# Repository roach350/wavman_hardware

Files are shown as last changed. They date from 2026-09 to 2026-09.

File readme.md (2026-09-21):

# WAVMAN Hardware
## WAVMAN Overview
WAVMAN is an open source portable PCM audio player based around the ATSAMD21 serieis of microcontrollers and the PCM5102 DAC. It supports SD via an SPI interface.

## Revisions and Notes
### REV 0
- Wrong symbol for USB-C resulting in only one pair of DP/DM being connected
- DAC does not have 3.3v on VDDIO or VDDIN
- PCM_MUTE (DAC mute) is not connected to MCU or even a pull up resistor to 3.3v so DAC is always muted by default
- The hold switch was botched (not connected to MCU and wrong net for power)
- All displays sink current from the LDO instaed of the battery directly, it may be desirable to change this
- No dedicated debug port for SWCLK and SWDIO
- The audio amp. has is missing several compontents (feedback resistors Rf and decoupling cap.)
- AMP_SHUTDOWN is not connected to the MCU
### REV 1
- should fix all major issues with REV 0
- minor tweaks to switch and knob placement
- 0805 passive components
- rerouted audio ICs
- knockout silkscreen for userfacing text

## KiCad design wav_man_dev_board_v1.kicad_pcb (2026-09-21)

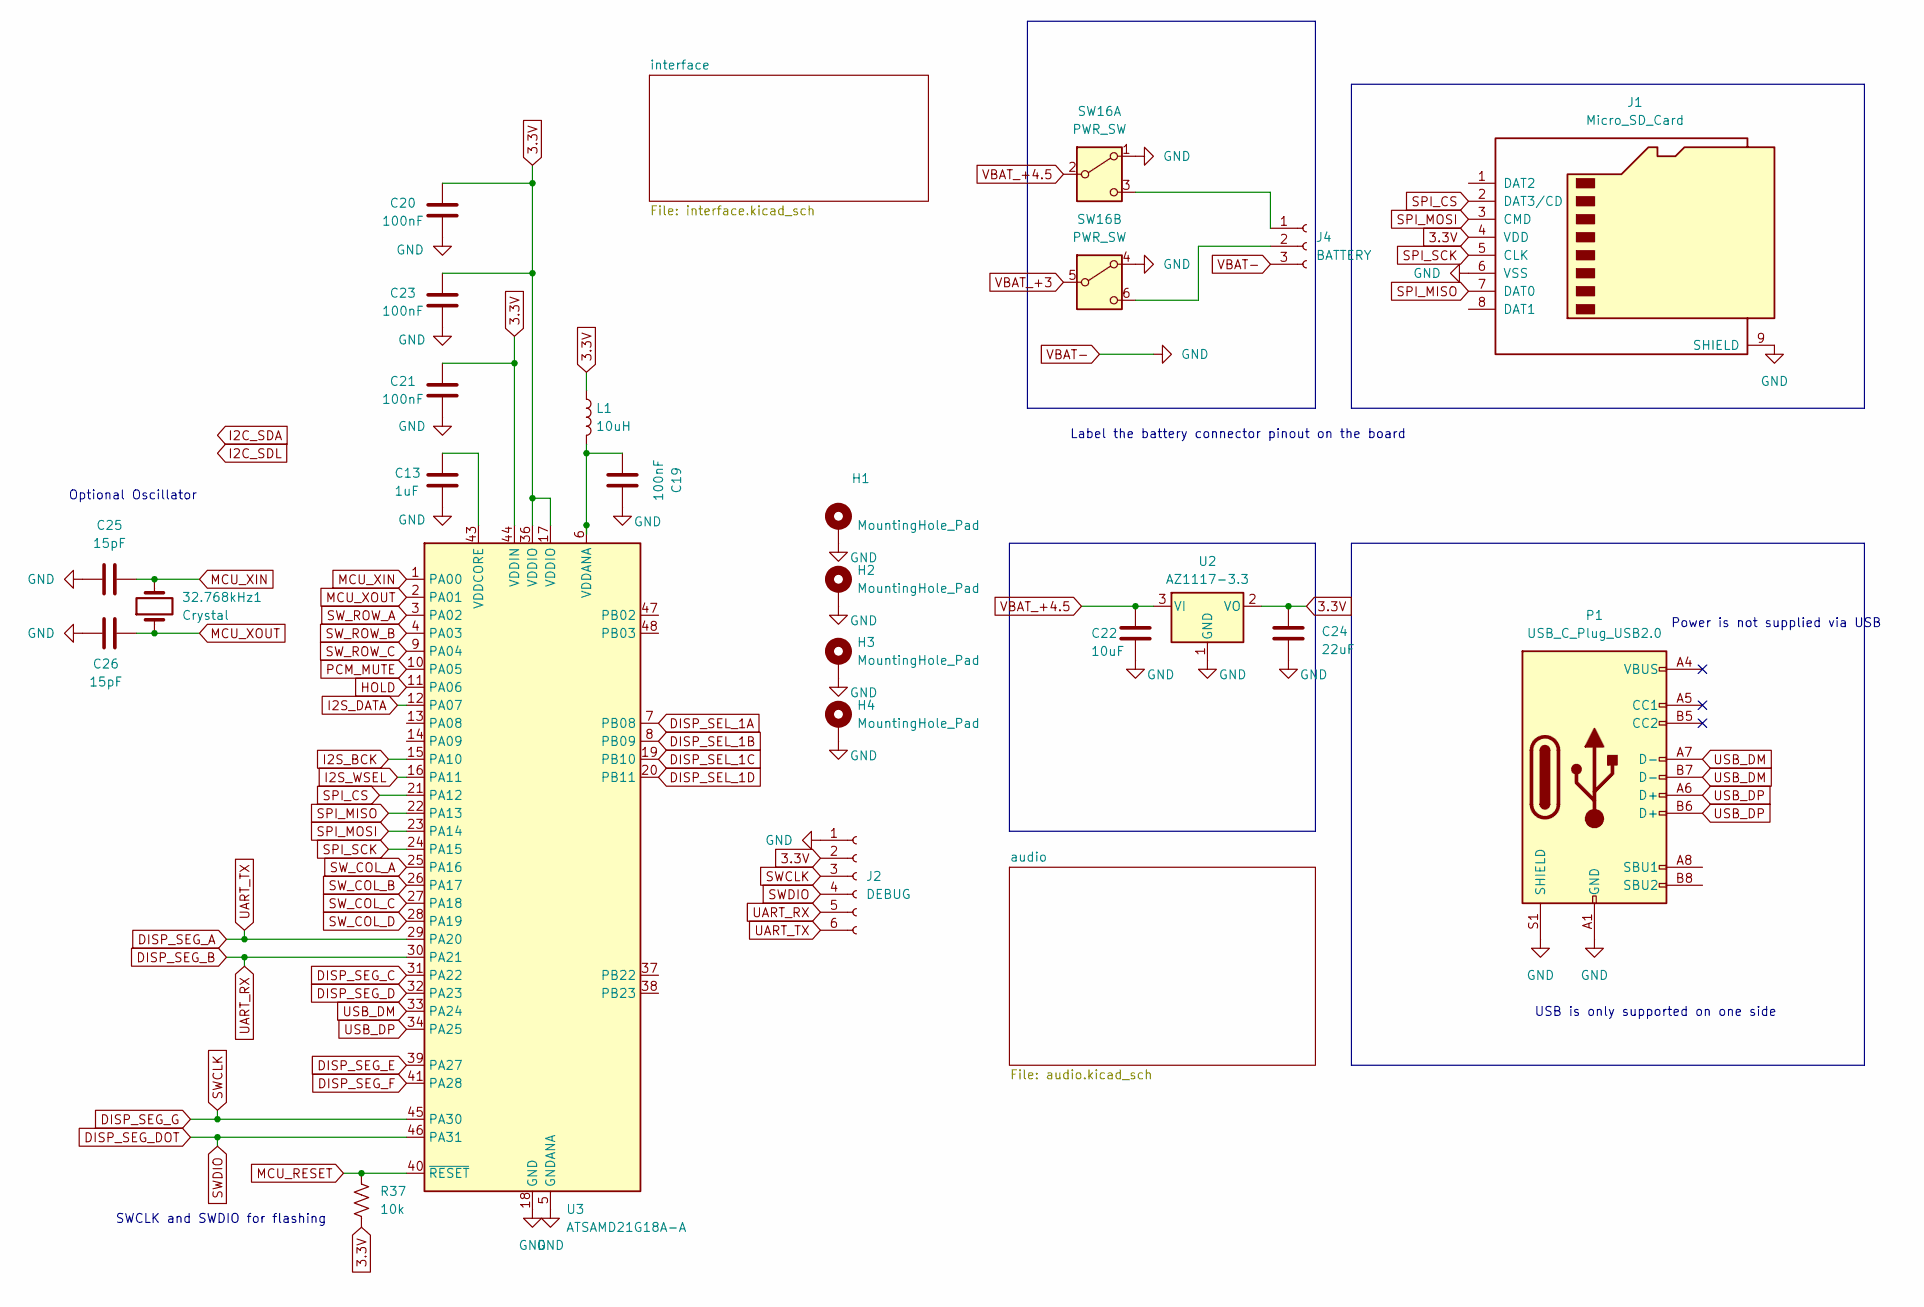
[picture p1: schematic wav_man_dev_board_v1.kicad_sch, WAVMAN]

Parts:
32.768kHz1: Crystal; Crystal_HC49-U_Vertical
C13: 1uF; C_0805_2012Metric_Pad1.18x1.45mm_HandSolder
C19, C20, C21, C23: 100nF; C_0805_2012Metric_Pad1.18x1.45mm_HandSolder
C22: 10uF; C_0805_2012Metric_Pad1.18x1.45mm_HandSolder
C24: 22uF; C_0805_2012Metric_Pad1.18x1.45mm_HandSolder
C25, C26: 15pF; C_0805_2012Metric_Pad1.18x1.45mm_HandSolder
H1, H2, H3, H4: MountingHole_Pad; MountingHole_2.7mm_M2.5_DIN965_Pad
J1: Micro_SD_Card; microSD_HC_Molex_47219-2001
J2: DEBUG; PinSocket_1x06_P2.54mm_Vertical
J4: BATTERY; JST_PH_B3B-PH-K_1x03_P2.00mm_Vertical
L1: 10uH; L_0805_2012Metric_Pad1.15x1.40mm_HandSolder
P1: USB_C_Plug_USB2.0; USB_C_Receptacle_GCT_USB4105-xx-A_16P_TopMnt_Horizontal
R37: 10k; R_0805_2012Metric_Pad1.20x1.40mm_HandSolder
SW16: PWR_SW; SW_E-Switch_EG2219_DPDT_Angled
U2: AZ1117-3.3; SOT-223-3_TabPin2
U3: ATSAMD21G18A-A; TQFP-48_7x7mm_P0.5mm

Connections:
3.3V: C20.1, C21.1, C23.1, C24.1, J1.4 (VDD), J2.2, L1.1, R37.2, U2.2 (VO), U3.17 (VDDIO), U3.36 (VDDIO), U3.44 (VDDIN); also elsewhere on the board
DISP_SEG_A: J2.6, U3.29 (PA20); also elsewhere on the board
DISP_SEG_B: J2.5, U3.30 (PA21); also elsewhere on the board
DISP_SEG_C: U3.31 (PA22); also elsewhere on the board
DISP_SEG_D: U3.32 (PA23); also elsewhere on the board
DISP_SEG_DOT: J2.4, U3.46 (PA31); also elsewhere on the board
DISP_SEG_E: U3.39 (PA27); also elsewhere on the board
DISP_SEG_F: U3.41 (PA28); also elsewhere on the board
DISP_SEG_G: J2.3, U3.45 (PA30); also elsewhere on the board
DISP_SEL_1A: U3.7 (PB08); also elsewhere on the board
DISP_SEL_1B: U3.8 (PB09); also elsewhere on the board
DISP_SEL_1C: U3.19 (PB10); also elsewhere on the board
DISP_SEL_1D: U3.20 (PB11); also elsewhere on the board
HOLD: U3.11 (PA06); also elsewhere on the board
I2S_BCK: U3.15 (PA10); also elsewhere on the board
I2S_DATA: U3.12 (PA07); also elsewhere on the board
I2S_WSEL: U3.16 (PA11); also elsewhere on the board
MCU_RESET: R37.1, U3.40 (~RESET); also elsewhere on the board
MCU_XIN: 32.768kHz1.2, C25.2, U3.1 (PA00); also elsewhere on the board
MCU_XOUT: 32.768kHz1.1, C26.2, U3.2 (PA01); also elsewhere on the board
unnamed: J4.1, SW16.3 (C)
unnamed: J4.2, SW16.6 (C)
unnamed: P1.A4 (VBUS), P1.A9 (VBUS), P1.B4 (VBUS), P1.B9 (VBUS)
unnamed: C19.1, L1.2, U3.6 (VDDANA)
unnamed: C13.2, U3.43 (VDDCORE)
PCM_MUTE: U3.10 (PA05); also elsewhere on the board
SPI_CS: J1.2 (DAT3/CD), U3.21 (PA12)
SPI_MISO: J1.7 (DAT0), U3.22 (PA13)
SPI_MOSI: J1.3 (CMD), U3.23 (PA14)
SPI_SCK: J1.5 (CLK), U3.24 (PA15)
SW_COL_A: U3.25 (PA16); also elsewhere on the board
SW_COL_B: U3.26 (PA17); also elsewhere on the board
SW_COL_C: U3.27 (PA18); also elsewhere on the board
SW_COL_D: U3.28 (PA19); also elsewhere on the board
SW_ROW_A: U3.3 (PA02); also elsewhere on the board
SW_ROW_B: U3.4 (PA03); also elsewhere on the board
SW_ROW_C: U3.9 (PA04); also elsewhere on the board
USB_DM: P1.A7 (D-), P1.B7 (D-), U3.33 (PA24)
USB_DP: P1.A6 (D+), P1.B6 (D+), U3.34 (PA25)
VBAT-: C13.1, C19.2, C20.2, C21.2, C22.2, C23.2, C24.2, C25.1, C26.1, H1.1, H2.1, H3.1, H4.1, J1.6 (VSS), J1.9 (SHIELD), J2.1, J4.3, P1.A1 (GND), P1.A12 (GND), P1.B1 (GND), P1.B12 (GND), P1.S1 (SHIELD), SW16.1 (A), SW16.4 (A), U2.1 (GND), U3.5 (GNDANA), U3.18 (GND), U3.35 (GND), U3.42 (GND); also elsewhere on the board
VBAT_+3: SW16.5 (B)
VBAT_+4.5: C22.1, SW16.2 (B), U2.3 (VI)

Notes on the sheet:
Power is not supplied via USB
SWCLK and SWDIO for flashing
Label the battery connector pinout on the board
USB is only supported on one side
Optional Oscillator

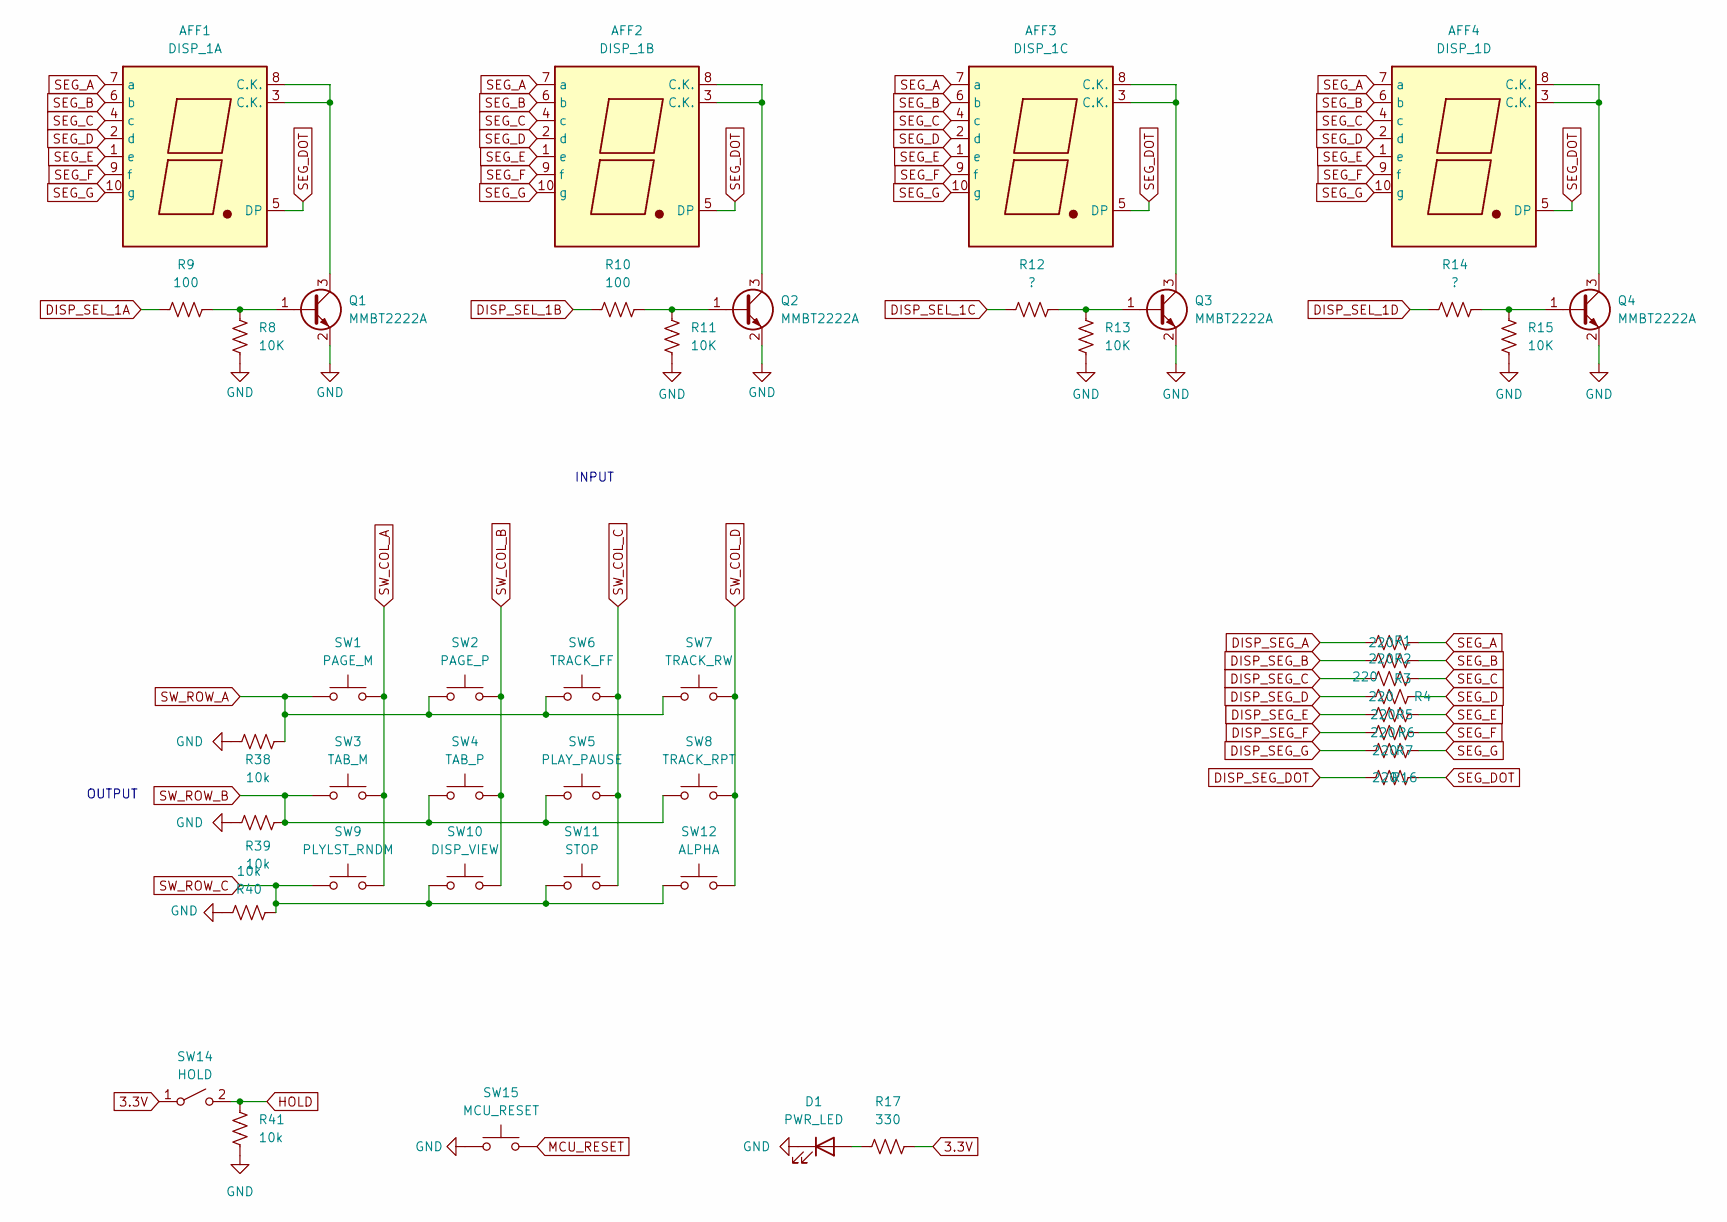
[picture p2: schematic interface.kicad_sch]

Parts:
AFF1: DISP_1A; 7SegmentLED_LTS6760_LTS6780
AFF2: DISP_1B; 7SegmentLED_LTS6760_LTS6780
AFF3: DISP_1C; 7SegmentLED_LTS6760_LTS6780
AFF4: DISP_1D; 7SegmentLED_LTS6760_LTS6780
D1: PWR_LED; LED_1206_3216Metric_Pad1.42x1.75mm_HandSolder
Q1, Q2, Q3, Q4: MMBT2222A; SOT-23_Handsoldering
R1, R2, R3, R4, R5, R6, R7, R16: 220; R_0805_2012Metric_Pad1.20x1.40mm_HandSolder
R8, R11, R13, R15: 10K; R_0805_2012Metric_Pad1.20x1.40mm_HandSolder
R9, R10: 100; R_0805_2012Metric_Pad1.20x1.40mm_HandSolder
R12, R14: ?; R_0805_2012Metric_Pad1.20x1.40mm_HandSolder
R17: 330; R_0805_2012Metric_Pad1.20x1.40mm_HandSolder
R38, R39, R40, R41: 10k; R_0805_2012Metric_Pad1.20x1.40mm_HandSolder
SW1: PAGE_M; SW_PUSH_6mm
SW2: PAGE_P; SW_PUSH_6mm
SW3: TAB_M; SW_PUSH_6mm
SW4: TAB_P; SW_PUSH_6mm
SW5: PLAY_PAUSE; SW_PUSH_6mm
SW6: TRACK_FF; SW_PUSH_6mm
SW7: TRACK_RW; SW_PUSH_6mm
SW8: TRACK_RPT; SW_PUSH_6mm
SW9: PLYLST_RNDM; SW_PUSH_6mm
SW10: DISP_VIEW; SW_PUSH_6mm
SW11: STOP; SW_PUSH_6mm
SW12: ALPHA; SW_PUSH_6mm
SW14: HOLD; SW_Slide_SPDT_Angled_CK_OS102011MA1Q
SW15: MCU_RESET; SW_PUSH_6mm

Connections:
3.3V: R17.2, SW14.1 (A); also elsewhere on the board
DISP_SEG_A: R1.1; also elsewhere on the board
DISP_SEG_B: R2.1; also elsewhere on the board
DISP_SEG_C: R3.1; also elsewhere on the board
DISP_SEG_D: R4.1; also elsewhere on the board
DISP_SEG_DOT: R16.1; also elsewhere on the board
DISP_SEG_E: R5.1; also elsewhere on the board
DISP_SEG_F: R6.1; also elsewhere on the board
DISP_SEG_G: R7.1; also elsewhere on the board
DISP_SEL_1A: R9.1; also elsewhere on the board
DISP_SEL_1B: R10.1; also elsewhere on the board
DISP_SEL_1C: R12.1; also elsewhere on the board
DISP_SEL_1D: R14.1; also elsewhere on the board
HOLD: R41.1, SW14.2 (B); also elsewhere on the board
MCU_RESET: SW15.2; also elsewhere on the board
unnamed: D1.2 (A), R17.1
unnamed: Q1.1 (B), R8.1, R9.2
unnamed: AFF1.3 (C.K.), AFF1.8 (C.K.), Q1.3 (C)
unnamed: Q2.1 (B), R10.2, R11.1
unnamed: AFF2.3 (C.K.), AFF2.8 (C.K.), Q2.3 (C)
unnamed: Q3.1 (B), R12.2, R13.1
unnamed: AFF3.3 (C.K.), AFF3.8 (C.K.), Q3.3 (C)
unnamed: Q4.1 (B), R14.2, R15.1
unnamed: AFF4.3 (C.K.), AFF4.8 (C.K.), Q4.3 (C)
SEG_A: AFF1.7 (a), AFF2.7 (a), AFF3.7 (a), AFF4.7 (a), R1.2
SEG_B: AFF1.6 (b), AFF2.6 (b), AFF3.6 (b), AFF4.6 (b), R2.2
SEG_C: AFF1.4 (c), AFF2.4 (c), AFF3.4 (c), AFF4.4 (c), R3.2
SEG_D: AFF1.2 (d), AFF2.2 (d), AFF3.2 (d), AFF4.2 (d), R4.2
SEG_DOT: AFF1.5 (DP), AFF2.5 (DP), AFF3.5 (DP), AFF4.5 (DP), R16.2
SEG_E: AFF1.1 (e), AFF2.1 (e), AFF3.1 (e), AFF4.1 (e), R5.2
SEG_F: AFF1.9 (f), AFF2.9 (f), AFF3.9 (f), AFF4.9 (f), R6.2
SEG_G: AFF1.10 (g), AFF2.10 (g), AFF3.10 (g), AFF4.10 (g), R7.2
SW_COL_A: SW1.2, SW3.2, SW9.2; also elsewhere on the board
SW_COL_B: SW2.2, SW4.2, SW10.2; also elsewhere on the board
SW_COL_C: SW5.2, SW6.2, SW11.2; also elsewhere on the board
SW_COL_D: SW7.2, SW8.2, SW12.2; also elsewhere on the board
SW_ROW_A: R38.2, SW1.1, SW2.1, SW6.1, SW7.1; also elsewhere on the board
SW_ROW_B: R39.2, SW3.1, SW4.1, SW5.1, SW8.1; also elsewhere on the board
SW_ROW_C: R40.2, SW9.1, SW10.1, SW11.1, SW12.1; also elsewhere on the board
VBAT-: D1.1 (K), Q1.2 (E), Q2.2 (E), Q3.2 (E), Q4.2 (E), R8.2, R11.2, R13.2, R15.2, R38.1, R39.1, R40.1, R41.2, SW15.1; also elsewhere on the board

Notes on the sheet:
OUTPUT
INPUT

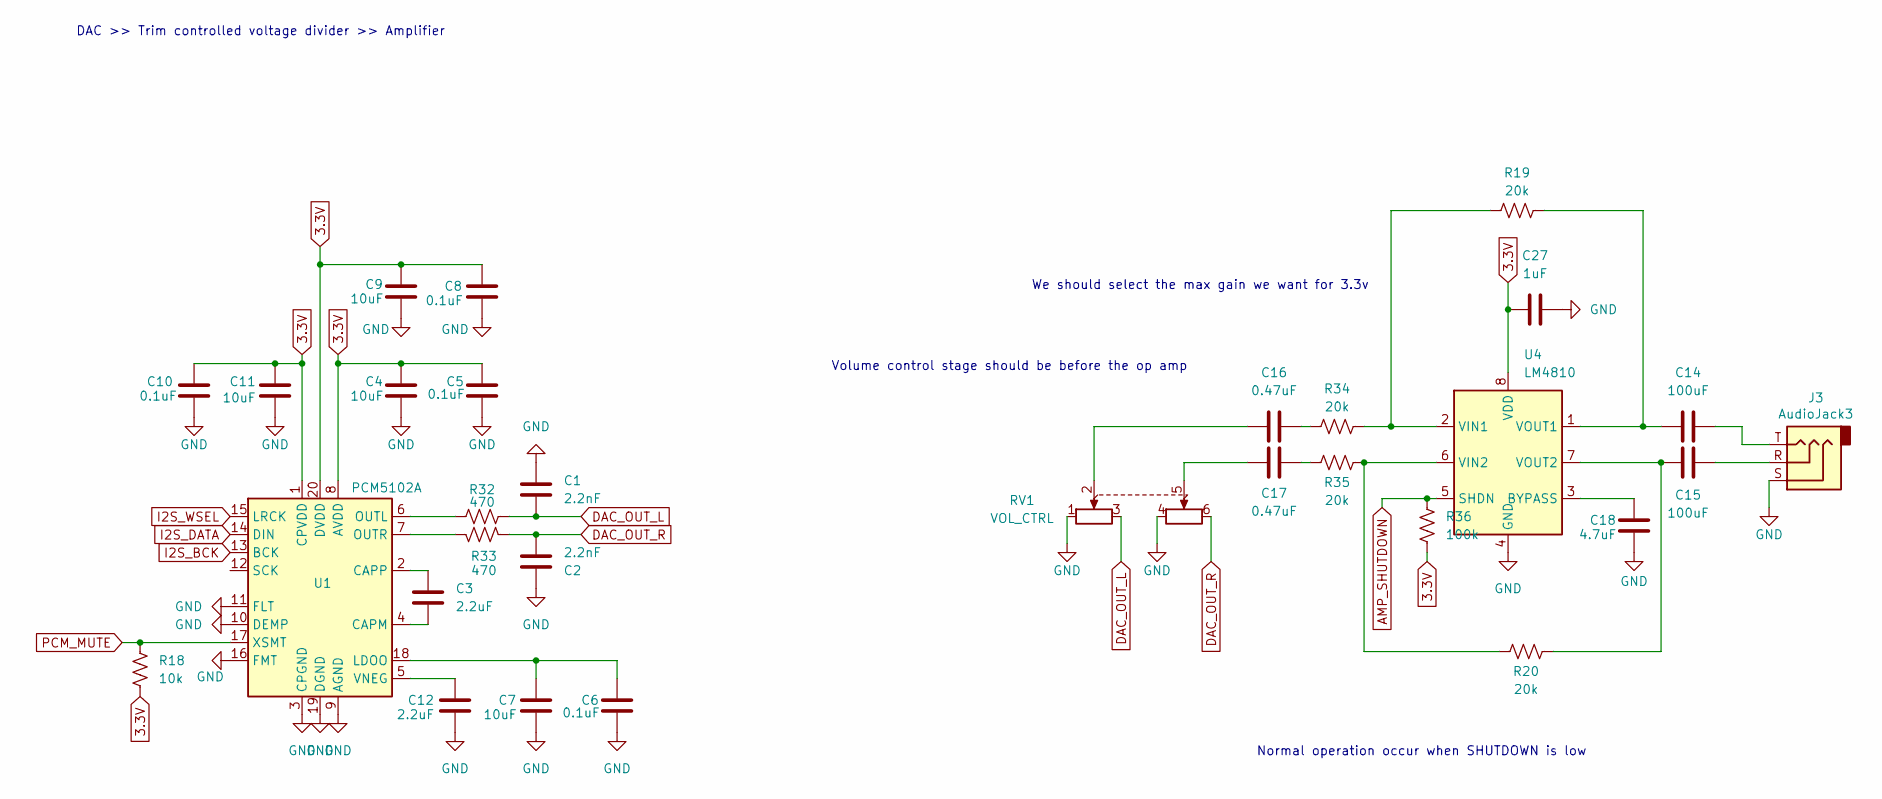
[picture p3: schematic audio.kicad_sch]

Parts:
C1, C2: 2.2nF; C_0805_2012Metric_Pad1.18x1.45mm_HandSolder
C3, C12: 2.2uF; C_0805_2012Metric_Pad1.18x1.45mm_HandSolder
C4, C7, C9, C11: 10uF; C_0805_2012Metric_Pad1.18x1.45mm_HandSolder
C5, C6, C8, C10: 0.1uF; C_0805_2012Metric_Pad1.18x1.45mm_HandSolder
C14, C15: 100uF; C_1206_3216Metric_Pad1.33x1.80mm_HandSolder
C16, C17: 0.47uF; C_0805_2012Metric_Pad1.18x1.45mm_HandSolder
C18: 4.7uF; C_0805_2012Metric_Pad1.18x1.45mm_HandSolder
C27: 1uF; C_0805_2012Metric_Pad1.18x1.45mm_HandSolder
J3: AudioJack3; Jack_3.5mm_CUI_SJ1-3533NG_Horizontal
R18: 10k; R_0805_2012Metric_Pad1.20x1.40mm_HandSolder
R19, R20, R34, R35: 20k; R_0805_2012Metric_Pad1.20x1.40mm_HandSolder
R32, R33: 470; R_0805_2012Metric_Pad1.20x1.40mm_HandSolder
R36: 100k; R_0805_2012Metric_Pad1.20x1.40mm_HandSolder
RV1: VOL_CTRL; Potentiometer_Alps_RK097_Dual_Horizontal
U1: PCM5102A; TSSOP-20_4.4x6.5mm_P0.65mm
U4: LM4810; TSSOP-8_3x3mm_P0.65mm

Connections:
3.3V: C4.1, C5.1, C8.1, C9.1, C10.1, C11.1, C27.1, R18.2, R36.2, U1.1 (CPVDD), U1.8 (AVDD), U1.20 (DVDD), U4.8 (VDD); also elsewhere on the board
AMP_SHUTDOWN: R36.1, U4.5 (SHDN)
DAC_OUT_L: C1.2, R32.2, RV1.3
DAC_OUT_R: C2.2, R33.2, RV1.6
I2S_BCK: U1.13 (BCK); also elsewhere on the board
I2S_DATA: U1.14 (DIN); also elsewhere on the board
I2S_WSEL: U1.15 (LRCK); also elsewhere on the board
unnamed: C14.2, J3.T
unnamed: C15.2, J3.R
unnamed: C16.1, RV1.2
unnamed: C16.2, R34.1
unnamed: C17.1, RV1.5
unnamed: C17.2, R35.1
unnamed: C3.2, U1.4 (CAPM)
unnamed: C3.1, U1.2 (CAPP)
unnamed: C6.1, C7.1, U1.18 (LDOO)
unnamed: R32.1, U1.6 (OUTL)
unnamed: R33.1, U1.7 (OUTR)
unnamed: C12.1, U1.5 (VNEG)
unnamed: C18.1, U4.3 (BYPASS)
unnamed: R19.1, R34.2, U4.2 (VIN1)
unnamed: R20.1, R35.2, U4.6 (VIN2)
unnamed: C14.1, R19.2, U4.1 (VOUT1)
unnamed: C15.1, R20.2, U4.7 (VOUT2)
PCM_MUTE: R18.1, U1.17 (XSMT); also elsewhere on the board
VBAT-: C1.1, C2.1, C4.2, C5.2, C6.2, C7.2, C8.2, C9.2, C10.2, C11.2, C12.2, C18.2, C27.2, J3.S, RV1.1, RV1.4, U1.3 (CPGND), U1.9 (AGND), U1.10 (DEMP), U1.11 (FLT), U1.16 (FMT), U1.19 (DGND), U4.4 (GND); also elsewhere on the board

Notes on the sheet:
Volume control stage should be before the op amp
We should select the max gain we want for 3.3v
Normal operation occur when SHUTDOWN is low
DAC >> Trim controlled voltage divider >> Amplifier

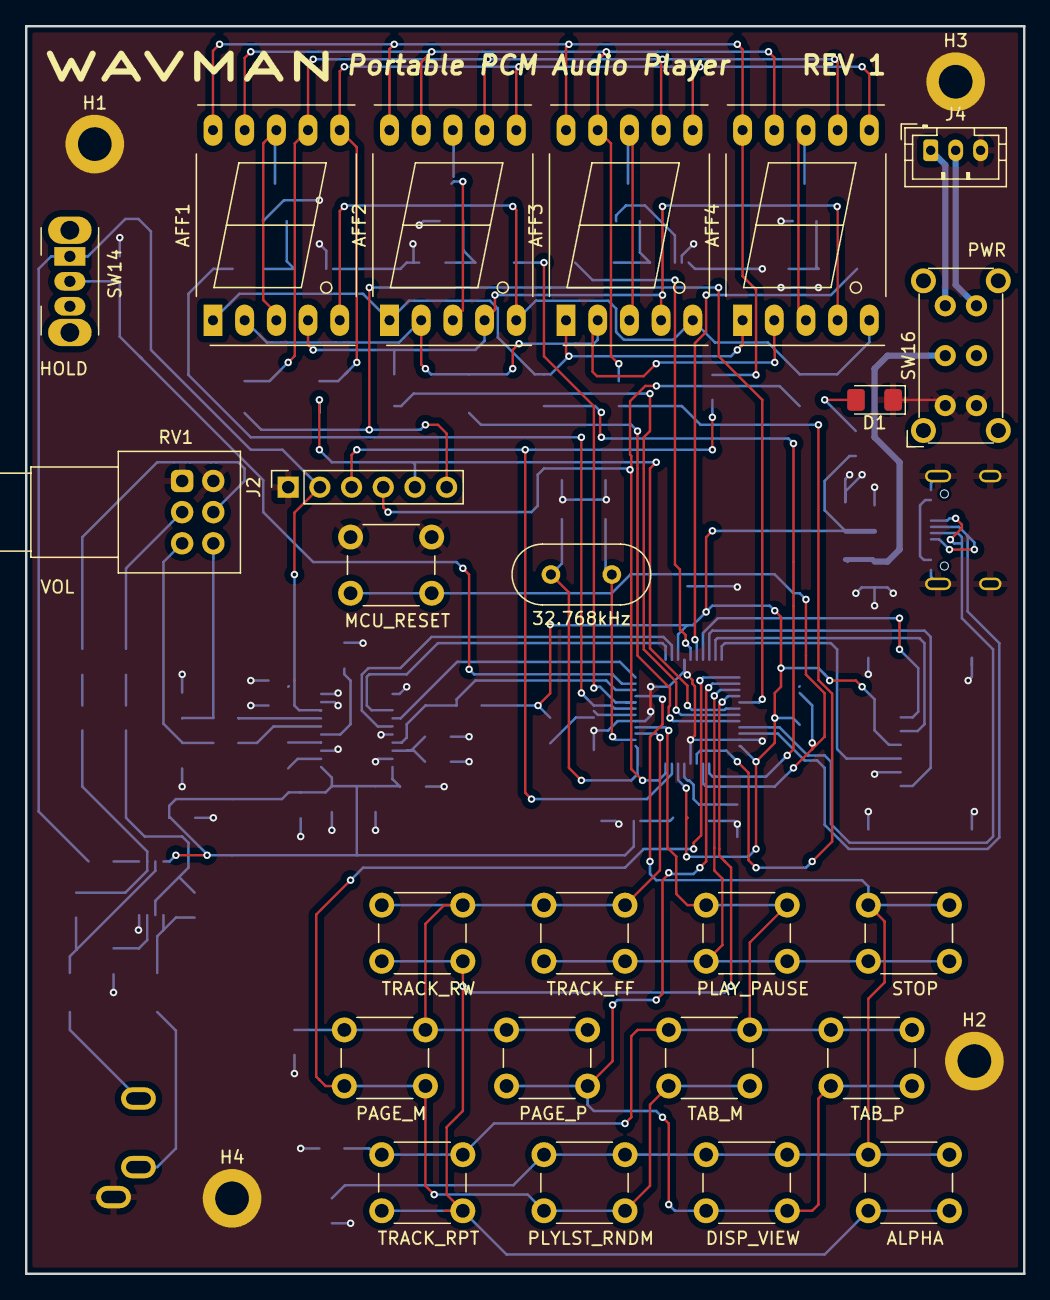
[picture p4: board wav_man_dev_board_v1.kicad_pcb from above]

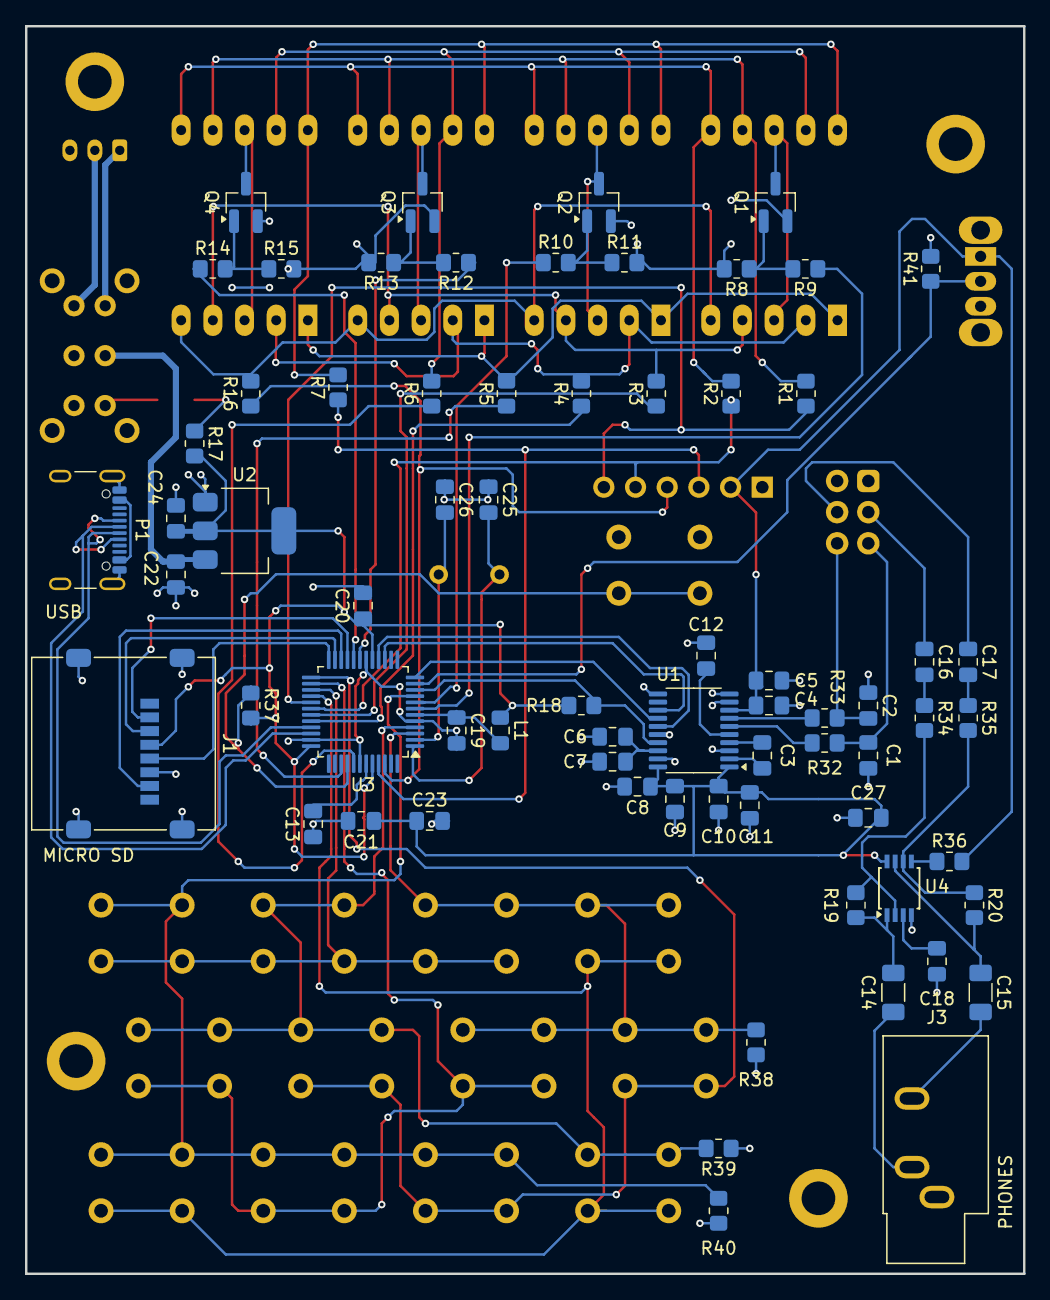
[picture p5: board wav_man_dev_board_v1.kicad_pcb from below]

Board: 2 copper layers, 80.0 x 100.0 mm, 97 parts (69 on the bottom side), 78 nets.

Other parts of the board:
32.768kHz: Crystal; Crystal_HC49-U_Vertical

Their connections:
MCU_XIN: 32.768kHz.2; also elsewhere on the board
MCU_XOUT: 32.768kHz.1; also elsewhere on the board

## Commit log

2026-08-25 updated schematic with v1 changes: fixed DAC power, added debug port, fixed mute and hold functionality
    [audio.kicad_sch, interface.kicad_sch, wav_man_dev_board_v1.kicad_sch]
2026-09-14 usb fixed, rerouted some traces
    [audio.kicad_sch, interface.kicad_sch, wav_man_dev_board_v1.kicad_pcb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]
2026-09-20 minor silkscreen and trace mods
    [wav_man_dev_board_v1.kicad_pcb]
2026-09-21 minor fixes to audio amp, updated readme
    [audio.kicad_sch, wav_man_dev_board_v1.kicad_pcb, wav_man_dev_board_v1.kicad_sch]
